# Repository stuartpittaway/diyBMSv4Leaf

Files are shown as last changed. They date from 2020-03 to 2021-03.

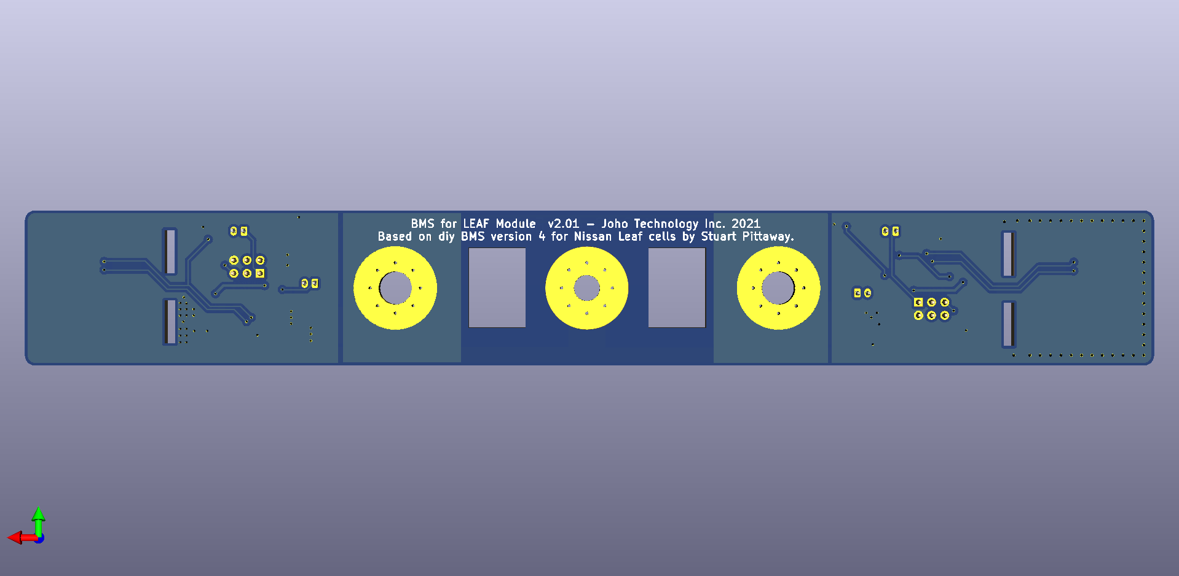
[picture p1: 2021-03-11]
Back-Design.png

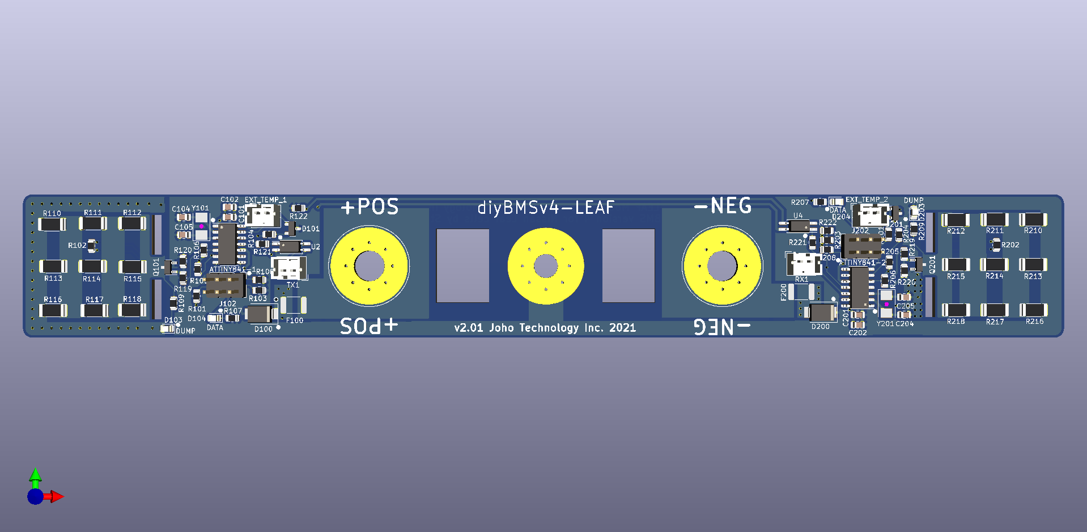
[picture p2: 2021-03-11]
Front-Design.png

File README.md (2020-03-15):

# diyBMS v4

Version 4 of the diyBMS for Nissan Leaf Cells

Do it yourself battery management system for Lithium ion battery packs/cells

This circuit revision has been made by George Boudreau - using the original v4 BMS design by Stuart Pittaway.

To contact George, please message on https://community.openenergymonitor.org/

# Videos on how to use and build

https://www.youtube.com/stuartpittaway

# CODE/SOFTWARE

Software and code for the modules and controller can now be found in a seperate repo

https://github.com/stuartpittaway/diyBMSv4Code

# WARNING

This is a DIY product/solution so don’t use this for safety critical systems or in any situation where there could be a risk to life.  

There is no warranty, it may not work as expected or at all.

The use of this project is done so entirely at your own risk.  It may involve electrical voltages which could kill - if in doubt, seek help.

The use of this project may not be compliant with local laws or regulations - if in doubt, seek help.

# License

This work is licensed under a Creative Commons Attribution-NonCommercial-ShareAlike 2.0 UK: England & Wales License.

https://creativecommons.org/licenses/by-nc-sa/2.0/uk/

You are free to:
* Share — copy and redistribute the material in any medium or format
* Adapt — remix, transform, and build upon the material
The licensor cannot revoke these freedoms as long as you follow the license terms.

Under the following terms:
* Attribution — You must give appropriate credit, provide a link to the license, and indicate if changes were made. You may do so in any reasonable manner, but not in any way that suggests the licensor endorses you or your use.
* Non-Commercial — You may not use the material for commercial purposes.
* ShareAlike — If you remix, transform, or build upon the material, you must distribute your contributions under the same license as the original.
* No additional restrictions — You may not apply legal terms or technological measures that legally restrict others from doing anything the license permits.

Notices:
You do not have to comply with the license for elements of the material in the public domain or where your use is permitted by an applicable exception or limitation.

No warranties are given. The license may not give you all of the permissions necessary for your intended use. For example, other rights such as publicity, privacy, or moral rights may limit how you use the material.

# Problem

A DIY Powerwall is the DIY construction of a pack of battery cells to create an energy store which can be used via inverters to power electrical items in the home. Generally cells are salvaged/second hand, and typically use Lithium 18650 cells.

Lithium batteries need to be kept at the same voltage level across a parallel pack. This is done by balancing each cell in the pack to raise or lower its voltage to match the others.

Existing balancing solutions are available in the market place, but at a relatively high cost compared to the cost of the battery bank, so this project is to design a low-cost, simple featured BMS/balancer.

# BMS Design

Design Goals: 
* Build upon my existing skill set and knowledge. 
* Building something that others can contribute to using regular standard libraries and off the shelf components.
* Build something that is inheriently safe
* Use platform.io to manage code and libraries
* Use Arduino based libraries and tools 
* Put everything on GITHUB
* Document it (always gets left to the end!)

# How it works

Controller provides human interface over Wifi/Web and also integrates with other systems like MQTT, emonCMS and Grafana.

Controller is esp8266-12e (NodeMCU v1) - although could be upgraded to ESP32 if really needed.

Controller should be able to take action on alerts/events to shut down inverters/chargers/fuses.

Each cell in a battery pack has a monitoring module.  This uses AVR ATTINY841 linked together by optoisolated serial ports for communication.

ATTINY841 provides:
* internal temperature monitoring
* external temperature monitoring
* Spare input/output for 3rd party use
* autonomous cell voltage balancing - it should still work even if controller is down

# How as v4 improved over v3?

* Code is better!
* Web interface no longer requires access to internet to download javascript libraries
* Controller provides outputs for integration with relay boards and switch gear
* Rules to control relay outputs
* Cell modules use ATTINY841 chip which provides more pins and lower power usage
* Removal of 3.3v regulator and ADUM chips lowers current usage significantly
* v3 module uses 10-12mA current constantly and v4 uses <1mA
* Dual temperature monitoring board + cells

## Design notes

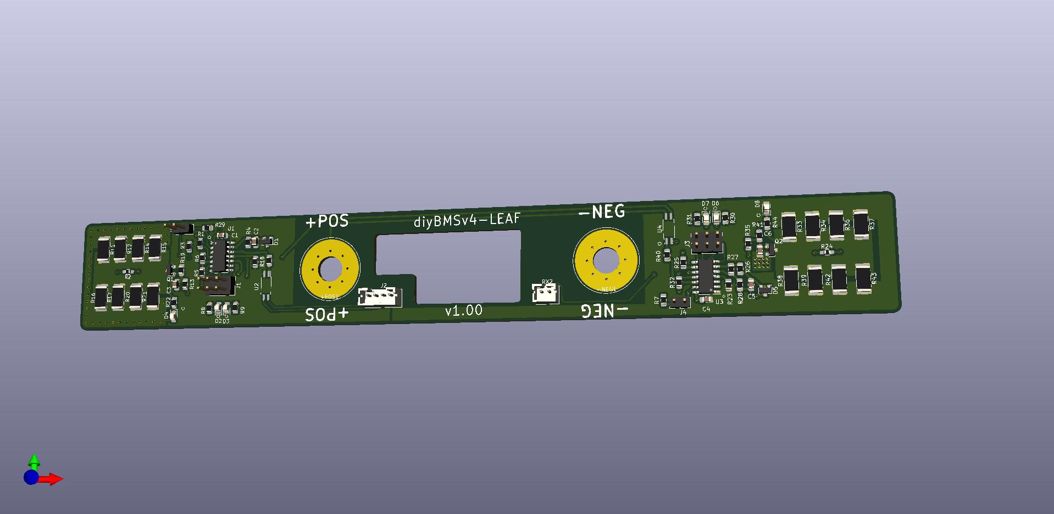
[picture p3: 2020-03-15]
diyBMS-Leaf-3D.jpg

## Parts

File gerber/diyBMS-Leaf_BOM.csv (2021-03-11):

Comment | Designator | Footprint | LCSC
ATtiny841-SSU | ATTINY841-1,ATTINY841-2 | Package_SO:SOIC-14_3.9x8.7mm_P1.27mm | C219103
100nF | C101,C201 | Capacitor_SMD:C_0805_2012Metric | C49678
1uF | C102,C202 | Capacitor_SMD:C_0805_2012Metric | C28323
22pF | C104,C105,C204,C205 | Capacitor_SMD:C_0805_2012Metric | C1804
SMBJ5.0A | D100,D200 | Diode_SMD:D_SMB | C440263
AZ432ANTR-E1 | D101,D201 | Package_TO_SOT_SMD:SOT-23 | C84139
DUMP | D103,D203 | LED_SMD:LED_0805_2012Metric | C84256
DATA | D104,D204 | LED_SMD:LED_0805_2012Metric | C84259
B2B-PH-K(LF)(SN) | EXT_TEMP_1,RX1,TX1,EXT_TEMP_2 | Connector_JST:JST_PH_B2B-PH-K_1x02_P2.00mm_Vertical | C2683610
mSMD150 | F100,F200 | Fuse:Fuse_1812_4532Metric | C70121
AVR-ISP-6 | J102,J202 | Connector_PinHeader_2.54mm:PinHeader_2x03_P2.54mm_Vertical | C65114
SM2320NSAC-TRG | Q101,Q201 | Package_TO_SOT_SMD:SOT-23 | C368560
10K | R101,R103,R108,R120,R201,R203,R208,R220 | Resistor_SMD:R_0805_2012Metric | C17414
CMFB103F3950FANT | R102,R202 | Resistor_SMD:R_0805_2012Metric | C51597
1K | R104,R204 | Resistor_SMD:R_0805_2012Metric | C17513
6.8K | R105,R205 | Resistor_SMD:R_0805_2012Metric | C17772
2.7K | R106,R206 | Resistor_SMD:R_0805_2012Metric | C17530
2K2 | R107,R109,R207,R209 | Resistor_SMD:R_0805_2012Metric | C17520
3.3OHM 3/4W | R110,R111,R112,R113,R114,R115,R116,R117,R118,R210,R211,R212,R213,R214,R215,R216,R217,R218 | Resistor_SMD:R_2010_5025Metric | C270971
510R | R119,R219 | Resistor_SMD:R_0805_2012Metric | C17734
220 | R121,R221 | Resistor_SMD:R_0805_2012Metric | 0805W8F2200T5E
4K7 | R122,R222 | Resistor_SMD:R_0805_2012Metric | C441984
EL3H7(B)(TA)-G | U2,U4 | Package_SO:SOP-4_4.4x2.6mm_P1.27mm | C32565
8MHZ Ceramic Resonator | Y101,Y201 | Crystal:Crystal_SMD_5032-2Pin_5.0x3.2mm | C115962

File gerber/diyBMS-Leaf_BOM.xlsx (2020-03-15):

COMMENT | Designator | Footprint | LSCS Part #
ATTing841-SSU | U1, U3 |  | C219103
100nF | C4,C1 | 0805 | C49678
2.2uF | C2, C5 | 0805 | C49217
10uF | C6,C3 | 0805 | C15850
AZ432ANTR-E1 | D5,D1 | SOT-23 | C84139
Green | D6,D2 | 0805 | C2297
Blue | D7,D3 | 0805 | C2293
RED | D8,D4 | 0805 | C84256
AO3400A | Q2,Q1 | SOT-23 | C20917
4.7K ohm | R10,R32 | 0805 | C17673
33 ohm | R21,R20,R17,R16,R15,R14,R12,R11,R42,R39,R38,R37,R36,R34,R33,R43 | 2512 | C53728
10K | R23,R1 | 0805 | C17414
NCP18WB473J03RB | R24,R2 | 0603 | C86142
1K ohm | R26,R4 | 0805 | C17513
68K | R27,R5 | 0805 | C17801
27K | R28,R6 | 0805 | C17593
47K ohm | R29,R41,R25,R19,R3,R7 | 0805 | C17713
510 ohm | R40,R18,R35,R13 | 0805 | C17734
2.2K | R44,R31,R30,R22,R9,R8 | 0805 | C17520
EL3H7(B)(TA)-G | U4,U2 | SOP-4_4.4x2.6mm_P1.27mm | C32565
B2B-PH-K-S (LF)(SN) | RX |  | C131337
B4B-PH-K(LF)(SN | J2 |  | C265289

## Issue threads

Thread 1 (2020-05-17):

Gerber&BOM update

baranchuk, 2020-05-17:
Need to correct gerber&BOM files to use with jlcpcb. Change thermistor to 0402 and AZ432ANTR-E1 to analog

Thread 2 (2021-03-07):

A updated version (still alpha) is being made by Allan Lind. How to intergrade/link the information?

robouden, 2021-03-07:
https://github.com/allanlind/diyBMSv4Leaf/releases/tag/v2.00-alpha

allanlind, 2021-03-07:
Hi Stuart, I am new to Github, and I hope my revised Leaf version of BMS can be useful. Let me know if you would like me to change anything.
Regards,
Allan

kchiem, 2021-03-09:
I got this error on JLCPCB:

"Failed processing the CPL file."

allanlind, 2021-03-09:
Stuart,
I used your version 4.40 that you release less than 2 weeks ago. It has the same identical parts. I increased the spacing and put copper under the resistors where possible and some slits to try to decouple the heat from the other parts of the board. Take a look at the PNG files to see the layout.
Allan

stuartpittaway, 2021-03-09:
Two weeks is a long time in diyBMS :-)

The original resistors were not high wattage, so were swapped out with 9 3/4W resistors.

Heres the latest picture of the 4.40 boards
https://github.com/stuartpittaway/diyBMSv4/blob/master/ModuleV440/ModuleV440.png

Additionally, JLCPCB didn't have stock of the original resistors!

allanlind, 2021-03-11:
Stuart, I updated the resistors. Please feel free to look at my updated version here:
https://github.com/allanlind/diyBMSv4Leaf/tree/diyBMSv4Leaf-ver2

allanlind, 2021-04-04:
Stuart, I got the new Leaf module boards back and will test them as the rest of the parts arrive. In the meantime I have a question for you regarding integration of diyBMS with Inverters. I have a Trinabess Power Box which has RS485 and I am wondering if it might be possible to get the diyBMS to work with it. Perhaps I can sniff the RS485 packets and figure out how to do things like set the charging current. Have you included any code in the controller for this by any chance?
Allan

stuartpittaway, 2021-04-05:
Hi Allan, Apart from testing that the RS485 works, I've not added in any additional code to talk to external devices (yet).  That is the plan though.

First item will be the new current shunt I've built (Modbus over RS485).

stuartpittaway, 2021-06-07:
@allanlind how is the updated LEAF board design?  A number of people have been asking about it.

allanlind, 2021-06-07:
Hi Stuart,
I have a bunch finished but have not been able to test as yet.
The holdup is with the Banggood displays.
Three units finally arrived but were banged up good!
Now they are saying they are out of stick again.
So I will have to accept a refund and look elsewhere.
Additionally I am still trying to source a suitable Leaf battery pack.
I should have something working soon.
I suspect the design is good though.

Allan Lind
Keitai (JPN): 080-5008-8699
Mobile (NZ): +64-22-100-8909
Sent from iPhone

On 8/06/2021, at 3:06 AM, Stuart Pittaway ***@***.***> wrote:

@allanlind<https://github.com/allanlind> how is the updated LEAF board design? A number of people have been asking about it.

—
You are receiving this because you were mentioned.
Reply to this email directly, view it on GitHub<https://github.com/stuartpittaway/diyBMSv4Leaf/issues/2#issuecomment-856015403>, or unsubscribe<https://github.com/notifications/unsubscribe-auth/ABNZKP676IKVMPXXMNB3EDLTRTN5VANCNFSM4YXLFYZA>.

allanlind, 2021-11-13:
The attachments won’t go through.

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

stuartpittaway, 2021-11-13:
Hi, the CANBUS doesn't really have a debug mode, but can be switched on by enabling the victron integration.

At the moment it is sending data out in victron BMS format.

allanlind, 2021-11-13:
How can I can send you photos?

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

stuartpittaway, 2021-11-13:
You can attach photos to GitHub issues

allanlind, 2021-11-13:
thanks,
I created a new issue for the CANBUS connection please take a look

allanlind, 2021-11-13:
New 7 in 1 Leaf module.

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

N1c084, 2022-03-07:
hi allanlind
Nice , did you post the files somewhere (gerber, schematic bom pcl....) ?
thanks

allanlind, 2022-03-15:
N1c084, I have uploaded 3.02 ver BOM, POS and GERBER files for this huge 7 module board. You have everything you need to get these manufactured at JLPCB. I had 20 boards made already. There was a small mistake which required drilling out a via on each board which I fixed in this 3.02 version. The only problem is going to be getting all the components. You may have to substitute for slightly different spec passives. Now the ATMEL CPUs are a real problem as JLCPCB never have them in stock. I had to manually solder 280 CPUs with an improvised cut down stencil and a rework station. It took a few days of work to do that, and not something to look forward to. You may have to look at getting board assembly done somewhere other than JLPCB.
As for the Schematic I will try to add the PDF file, but I first need to figure out why it's not displaying correctly.

N1c084, 2022-03-20:
Thanks you. i will look later. Do ou mount the PCB directly on terminals of cells or to you first mount the connexion bar witch can support more current flow?
Regards

allanlind, 2022-03-21:
The design includes high current path so no need to use bus bars. The board goes directly onto the modules.
I’ll double check the pos file for correct rotation.

N1c084, 2022-03-21:
Ok , please, how much current can pass trough the PCB?
I try to load pos file on Jl pcb and all 3 pin mosfet and regulator are
@180degree on final check screen.thanks

Le lun. 21 mars 2022 à 01:20, GammaKiwi ***@***.***> a écrit :

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

allanlind, 2022-03-21:
OK I’ll update the pos file tomorrow. The pcb tracks are likely good for 40A. I have 8 of these boards in parallel and have run 180A total without overheating which works out to 22A per board. But if you want to run very high current you can always put the original Leaf bus bars on as well.

allanlind, 2022-03-21:
I double checked the pos file and it is actually correct. Here is the response from JLCPCB:

"having trouble with pos file. In kicad all components are oriented correctly in 3D view
but when I check your layout preview the transistors and voltage references are rotated 180 deg"

Wick 09:50
Actually, sometimes not all files can be detected/recognized correctly by our system ,so you can ignore it and proceed.
Our engineer will check your file and if any issues, they will get you informed. Our engineer will correct it and you could check the DFM they make later.

N1c084, 2022-03-21:
ok thanks this is a JLPCB bug
You have 8 board in //, how do you drive the coupling of string (contactor for each string)  and security (open only the fail string and never closed a string with too diffèrent voltage /SOC from other)?
one controler board per  string?

N1c084, 2022-03-21:
and do you know if this board design is compatible with gen 4?
 i neeed to look if space between terminals are the same before put an order

allanlind, 2022-03-21:
Not sure what you mean by Gen 4. My design is for 24kwh Gen 1 or Gen 2 modules only. You cannot use 30 and 40kWh modules as these are different and the positive and negative terminals are arranged differently.
I have used 8 Chint 2 pole DZ158-125 MCBs to isolate each bank. These MCB are rated for 415VAC or 110VDC per pole and can break up to 125A DC.

allanlind, 2022-03-21:
Detail showing how the modules are wired to the MCBs.
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

This photo shows the bas bars where all 8 banks come together. You can also see a 160A per pole Circuit Breaker which allows me to isolate the two 5kW Victron inverters which are in parallel.
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
Breaking capacity on this circuit breaker is 40,000A.

N1c084, 2022-03-21:
thanks , nice.
But if a cell fail by going undervoltage or become hot, you can not isolate this string automatically , it can be better to add such security feature by driving a relay on each string?

allanlind, 2022-03-22:
Not sure how one would do that.

N1c084, 2022-03-22:
> Not sure how one would do that.

@stuartpittaway , any idea to drive one relay per string with voltage control between string before closed and also ability to isolate 1 faulty string and stay other alive?  Thanks

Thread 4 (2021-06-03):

CPL File missing

dakoal, 2021-06-03:
There is no "JLC" named BOM and CPL FIle here.
For the "normal" modules there are extra JLCPCB BOM and CPL files.

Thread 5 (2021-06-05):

kicad.pcb file can't be opened.

dakoal, 2021-06-05:
Can't open the file diyBMS-Leaf.kicad_pcb.
It says I need to install newer KiCad Version, but already have the newest.

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

stuartpittaway, 2021-06-07:
I think the last submitted update must have used the experimental version of KICAD 6, hence the issue with opening the board.

I don't maintain this version of the design, so would need somebody to help revive this version of the boards.

allanlind, 2021-11-13:
Oh sorry, just saw this now. Yes you need to download the Daily Build version of Kicad and you can then open the files.

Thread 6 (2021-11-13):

Trinabess Power Box Experiment

allanlind, 2021-11-13:
Experiment to connect Trinabess Power Box to DIYBMS Controller with CANBUS.
I got the CANBUS pinout from the US2000 battery as the Trinabess Inverter connects to it using the supplied cable. See pinout in attached image.

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

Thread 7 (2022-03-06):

Center tap as part of the PCB seems bad?

gesso15, 2022-03-06:
The initial design of the leaf board had the center tap on a wire that plugged in, this way you could attach the center tap before you attached the outer taps. This prevented you from accidentally sending 2s worth of voltage into the second monitor if the outer taps touched before the center tap.

I don't really understand how to do that with the current design that has the center tap as part of the PCB, without flexing the PCB.

Am I missing something?

N1c084, 2022-03-07:
originaly you connect the 2 outer first and after the center?
it is like a switch, in this design , noway to shutdown bms but no functionnal pb

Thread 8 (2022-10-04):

Leaf install photo

Deftaudio, 2022-10-04:
Hi,
I have 19 Leaf modules loaded in Vectrix VX1 EV scooter. Would love to use your adoption of DIYbms there.
Would you please share any photo of the finished/installed module. Just want to understand how it sits on buss bars and mounting.
Thank you!

stuartpittaway, 2022-10-05:
Hi, I didn't actually build/design the leaf modules they were done by the community over at the OpenEnergyMonitor forum.

You are best to ask over there for help.

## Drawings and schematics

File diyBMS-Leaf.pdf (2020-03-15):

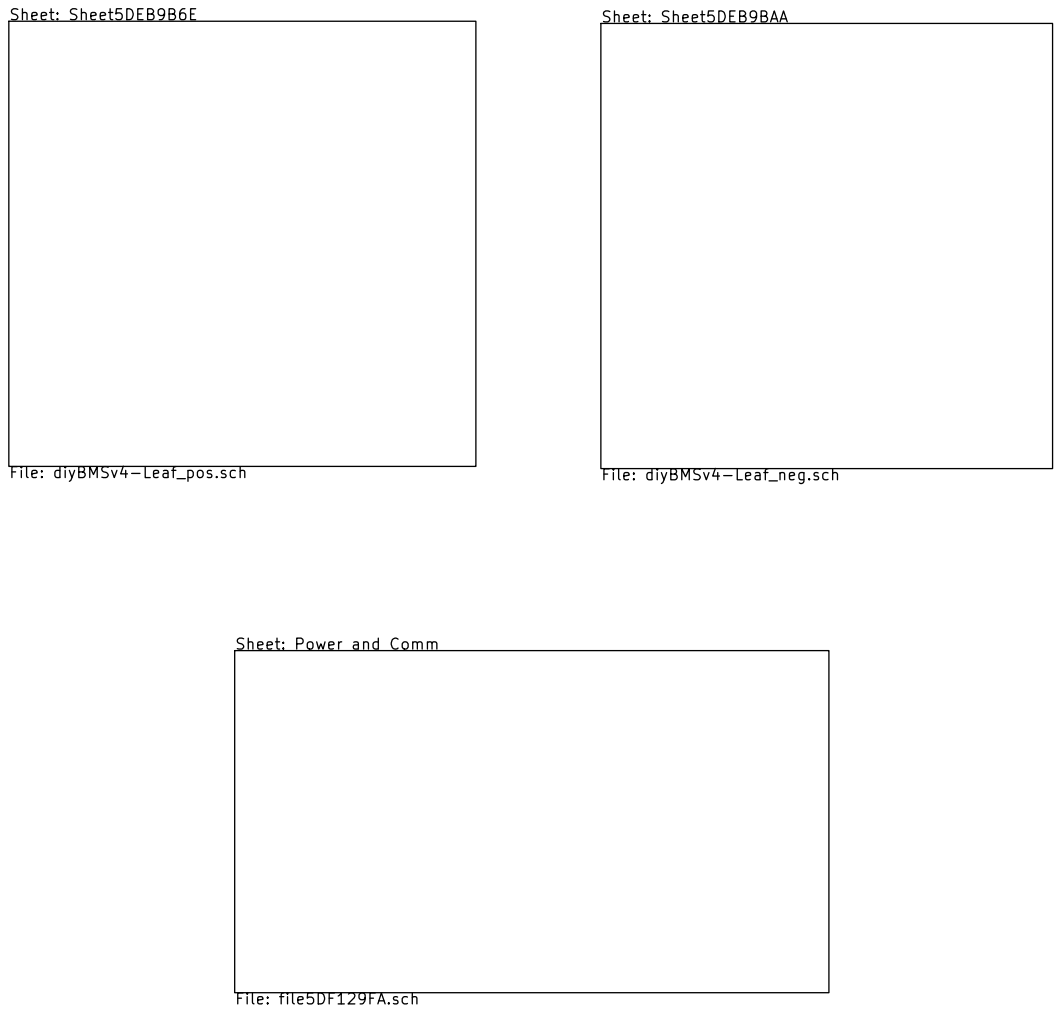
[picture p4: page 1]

File: diyBMSv4-Leaf_neg.sch Sheet: Power and Comm

Id: 1/4 Title: diyBMS-LEAF

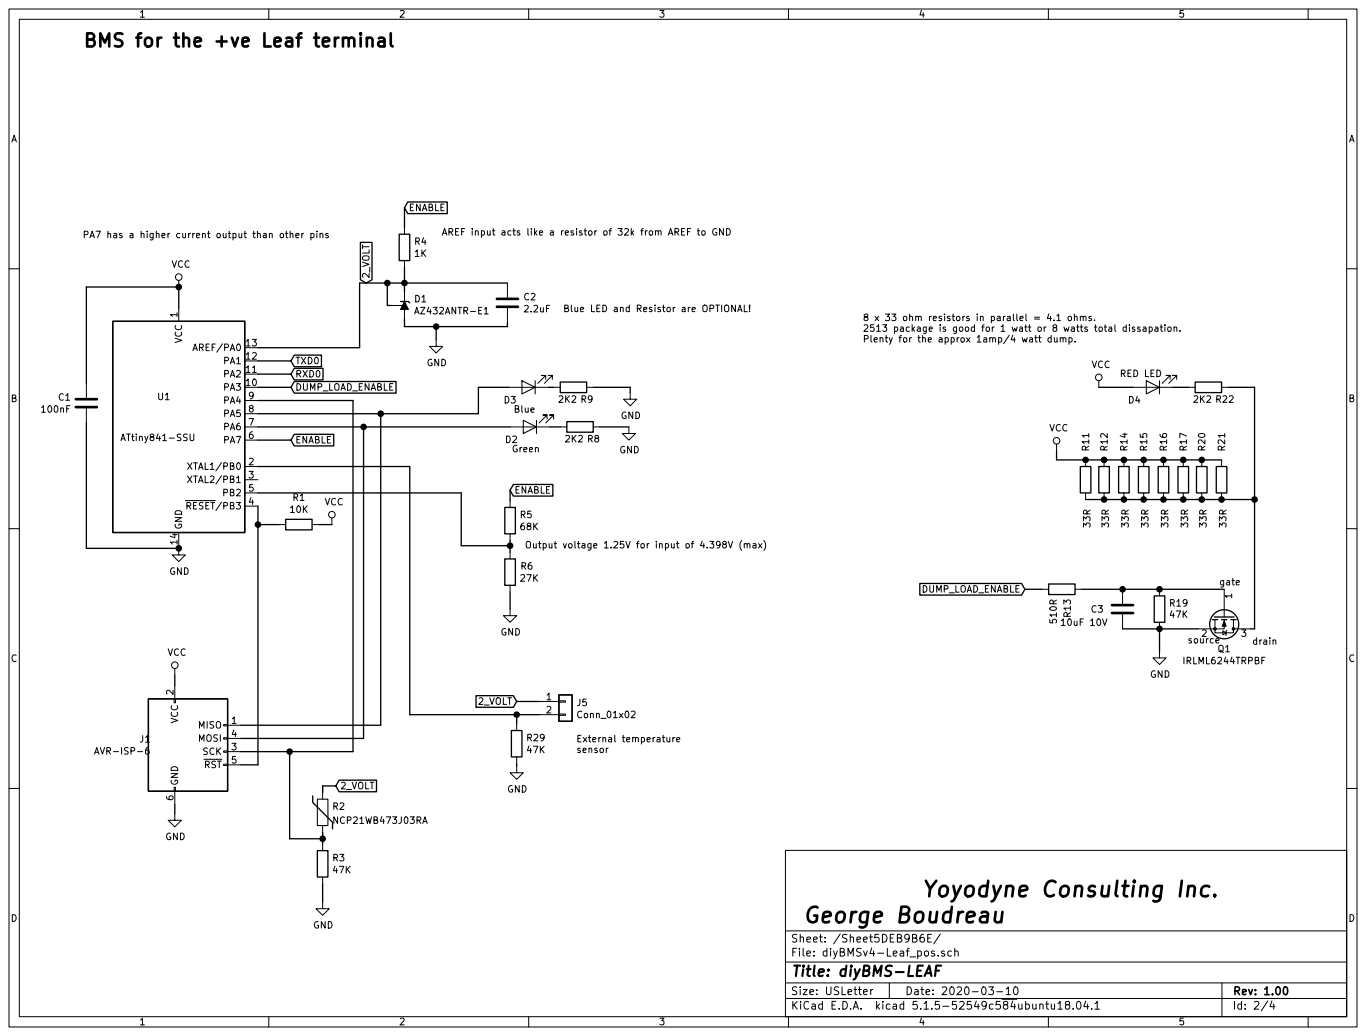
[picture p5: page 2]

BMS for the +ve Leaf terminal
2_VOLT ENABLE 2_VOLT

AREF input acts like a resistor of 32k from AREF to GND

gate PA7 has a higher current output than other pins

1 PA3 10 PA2 11 PA1 12 AREF/PA0 13 GND 14 XTAL1/PB0 2 XTAL2/PB1 3 RESET/PB3 4 PB2 5 PA7 6 PA6 7 PA5 8 PA4 U1 9 ATtiny841-SSU R21 33R R20 33R

8 x 33 ohm resistors in parallel = 4.1 ohms.
2513 package is good for 1 watt or 8 watts total dissapation.
Plenty for the approx 1amp/4 watt dump.

2 SCK 3 MOSI 4 RST 5 GND

File: diyBMSv4-Leaf_pos.sch Sheet: /Sheet5DEB9B6E/ Yoyodyne Consulting Inc.

Id: 2/4 Title: diyBMS-LEAF

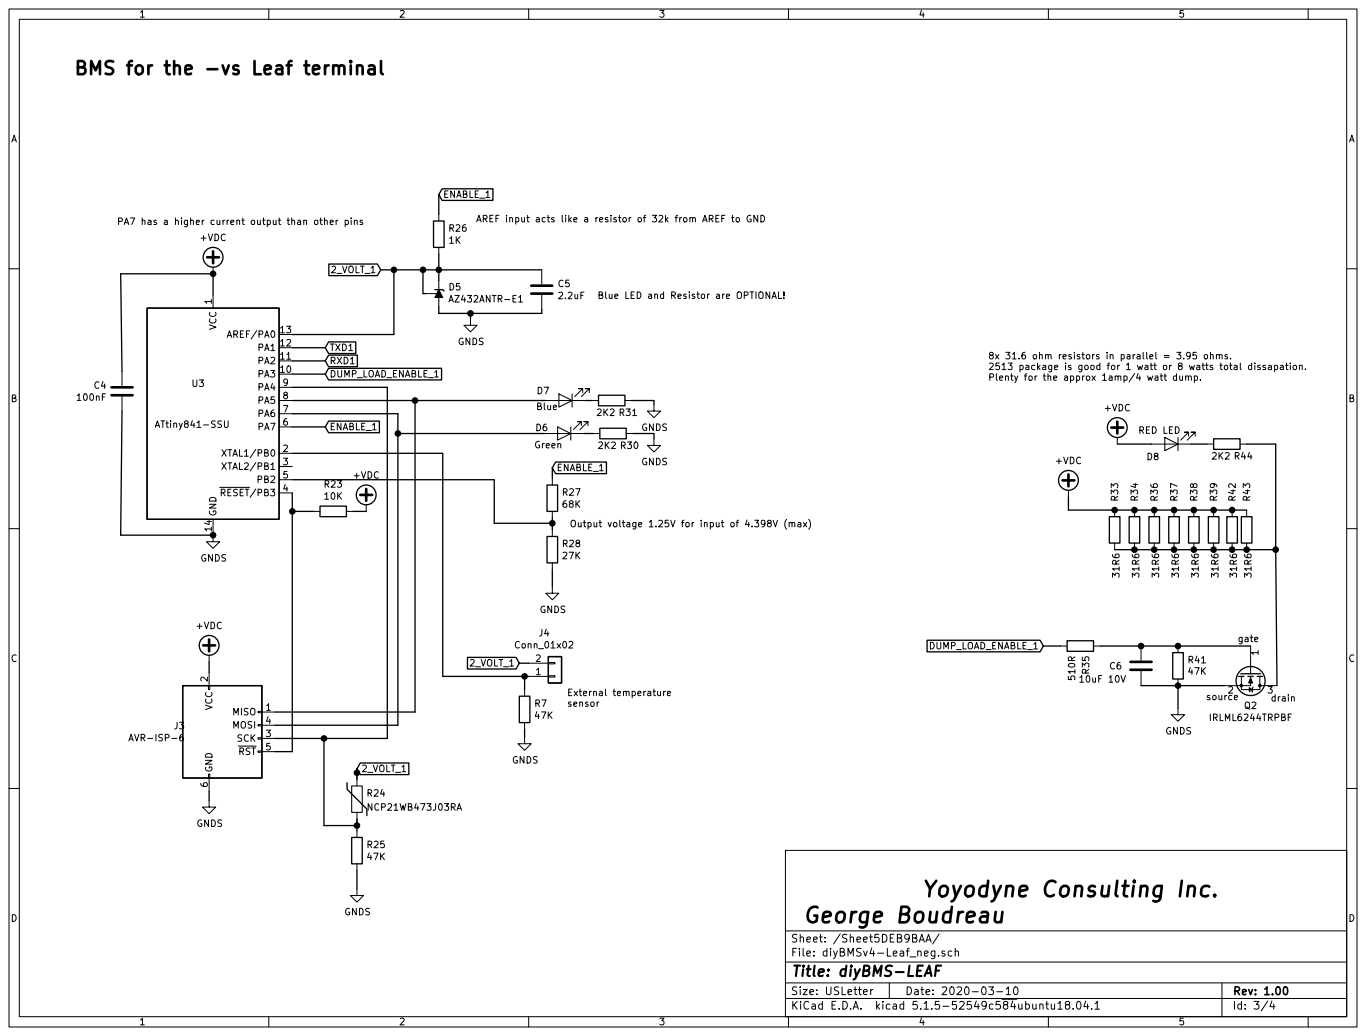
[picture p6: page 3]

BMS for the -vs Leaf terminal

AREF input acts like a resistor of 32k from AREF to GND

2_VOLT_1 TXD1 RXD1 PA7 has a higher current output than other pins

1 PA3 10 PA2 11 PA1 12 AREF/PA0 13 GND 14 XTAL1/PB0 2 XTAL2/PB1 3 RESET/PB3 4 PB2 5 PA7 6 PA6 7 PA5 8 PA4 U3 9 ATtiny841-SSU R43 31R6 C6

gate Blue LED and Resistor are OPTIONAL!

2513 package is good for 1 watt or 8 watts total dissapation.

+VDC
R23

Output voltage 1.25V for input of 4.398V (max)

2 SCK 3 MOSI 4 RST 5 GND

File: diyBMSv4-Leaf_neg.sch Sheet: /Sheet5DEB9BAA/ Yoyodyne Consulting Inc.

Id: 3/4 Title: diyBMS-LEAF

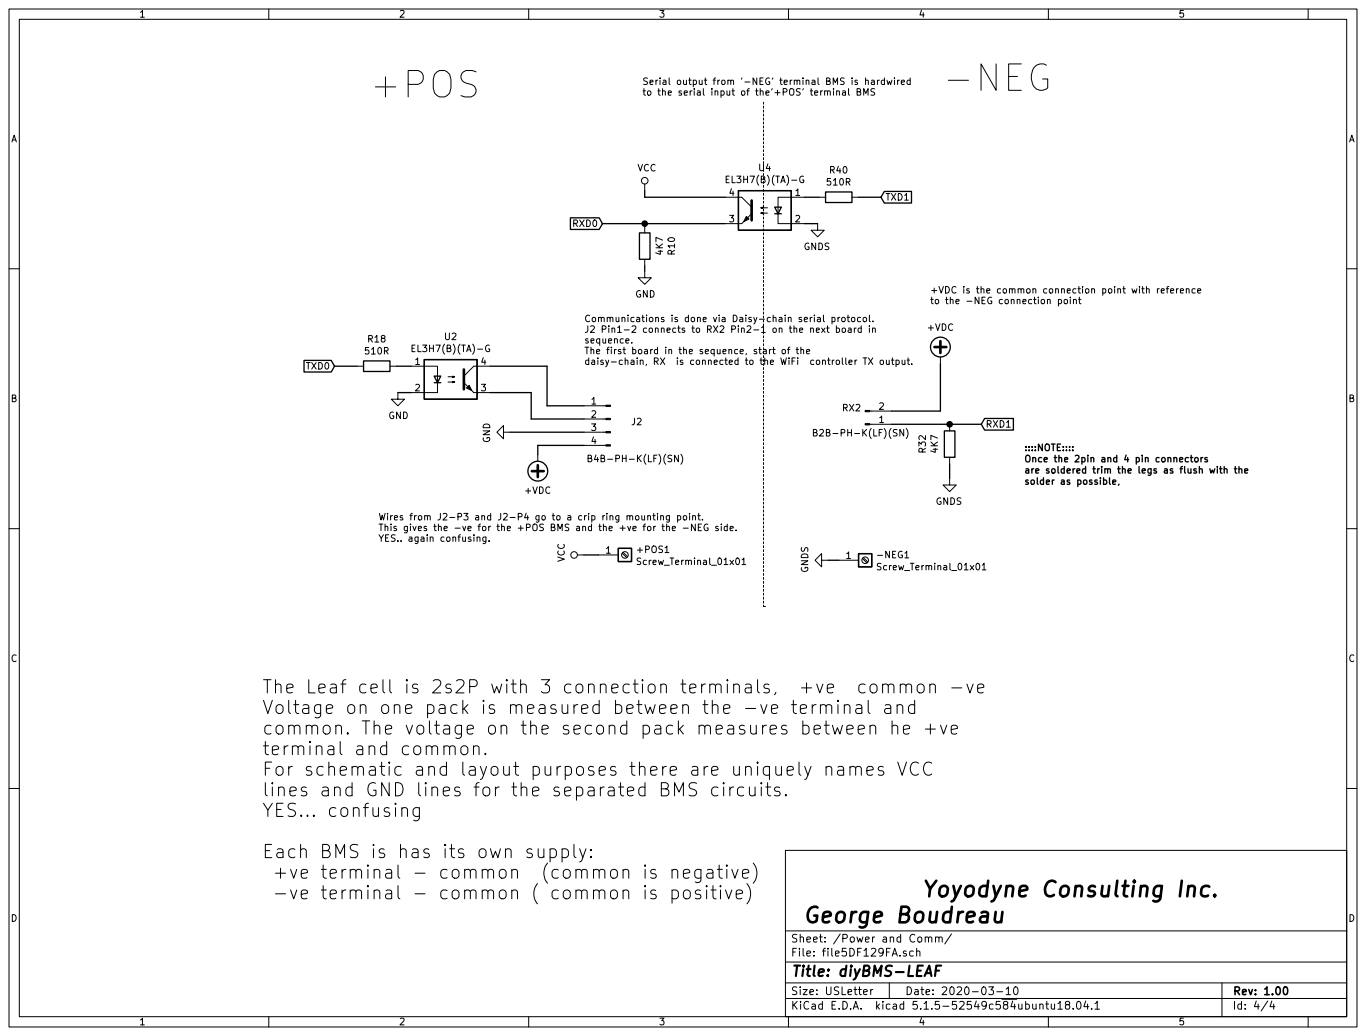
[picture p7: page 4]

+VDC is the common connection point with reference
to the -NEG connection point

Communications is done via Daisy-chain serial protocol. J2 Pin1-2 connects to RX2 Pin2-1 on the next board in

sequence. The first board in the sequence, start of the

daisy-chain, RX is connected to the WiFi controller TX output.

J2 B4B-PH-K(LF)(SN) GND

::::NOTE:::: Once the 2pin and 4 pin connectors

are soldered trim the legs as flush with the
solder as possible,

Wires from J2-P3 and J2-P4 go to a crip ring mounting point.
This gives the -ve for the +POS BMS and the +ve for the -NEG side.
YES.. again confusing.

Voltage on one pack is measured between the -ve terminal and
common. The voltage on the second pack measures between he +ve
terminal and common.
For schematic and layout purposes there are uniquely names VCC
lines and GND lines for the separated BMS circuits.
YES... confusing

Each BMS is has its own supply:
-ve terminal - common ( common is positive)

File: file5DF129FA.sch Sheet: /Power and Comm/ Yoyodyne Consulting Inc.

Id: 4/4 Title: diyBMS-LEAF

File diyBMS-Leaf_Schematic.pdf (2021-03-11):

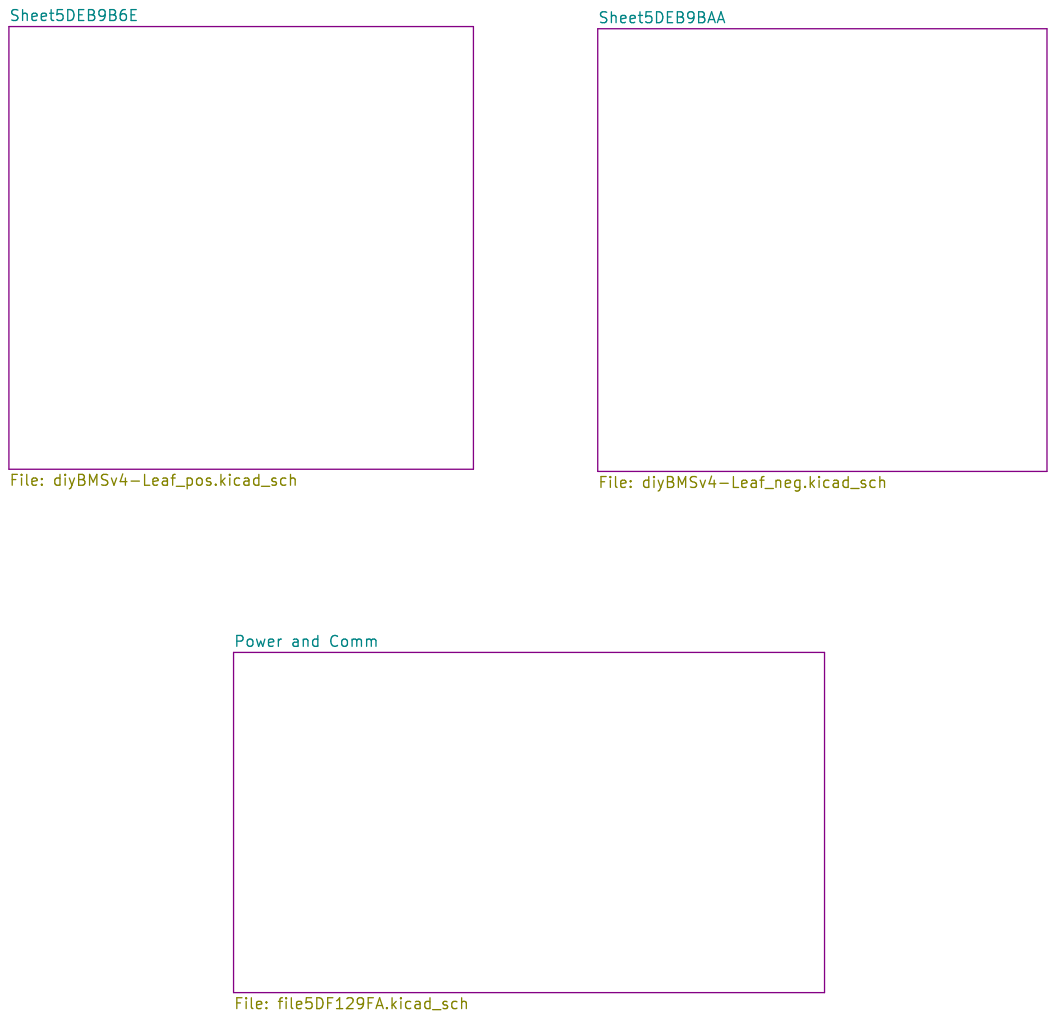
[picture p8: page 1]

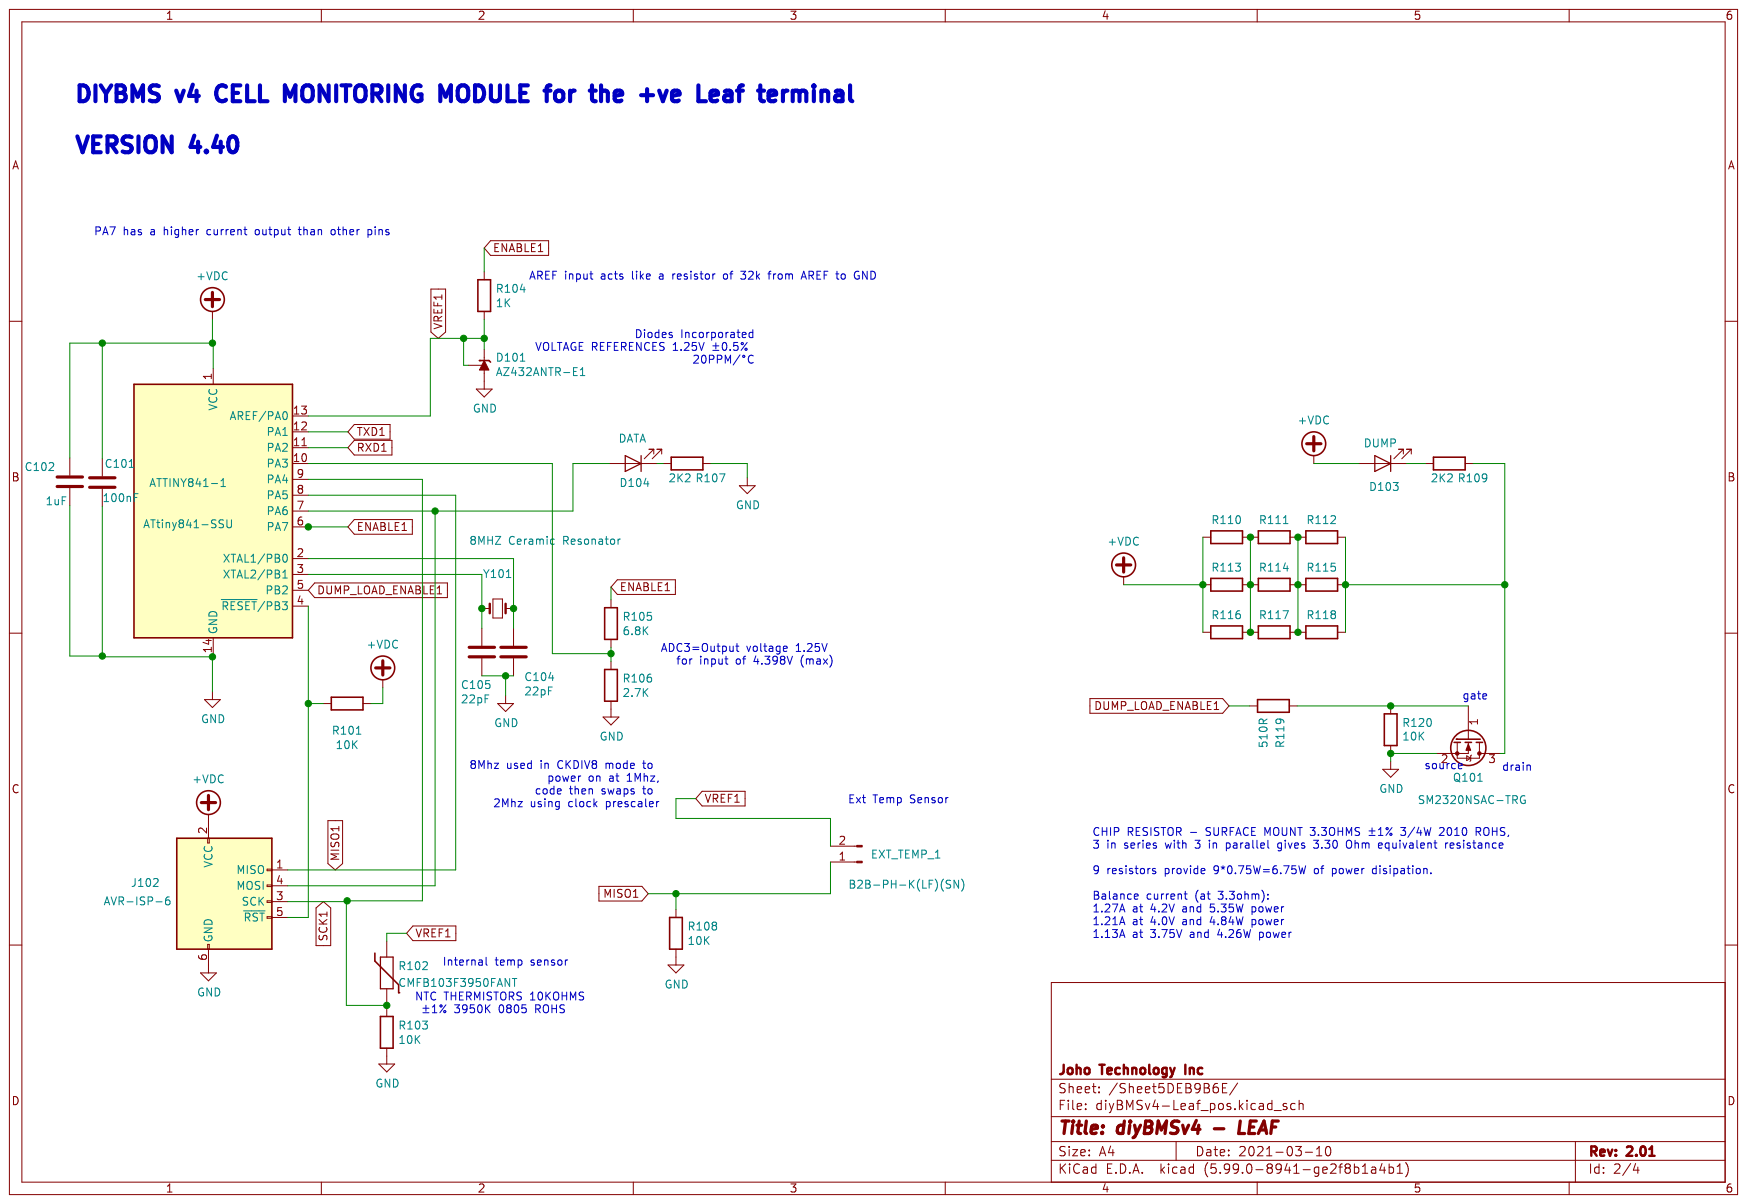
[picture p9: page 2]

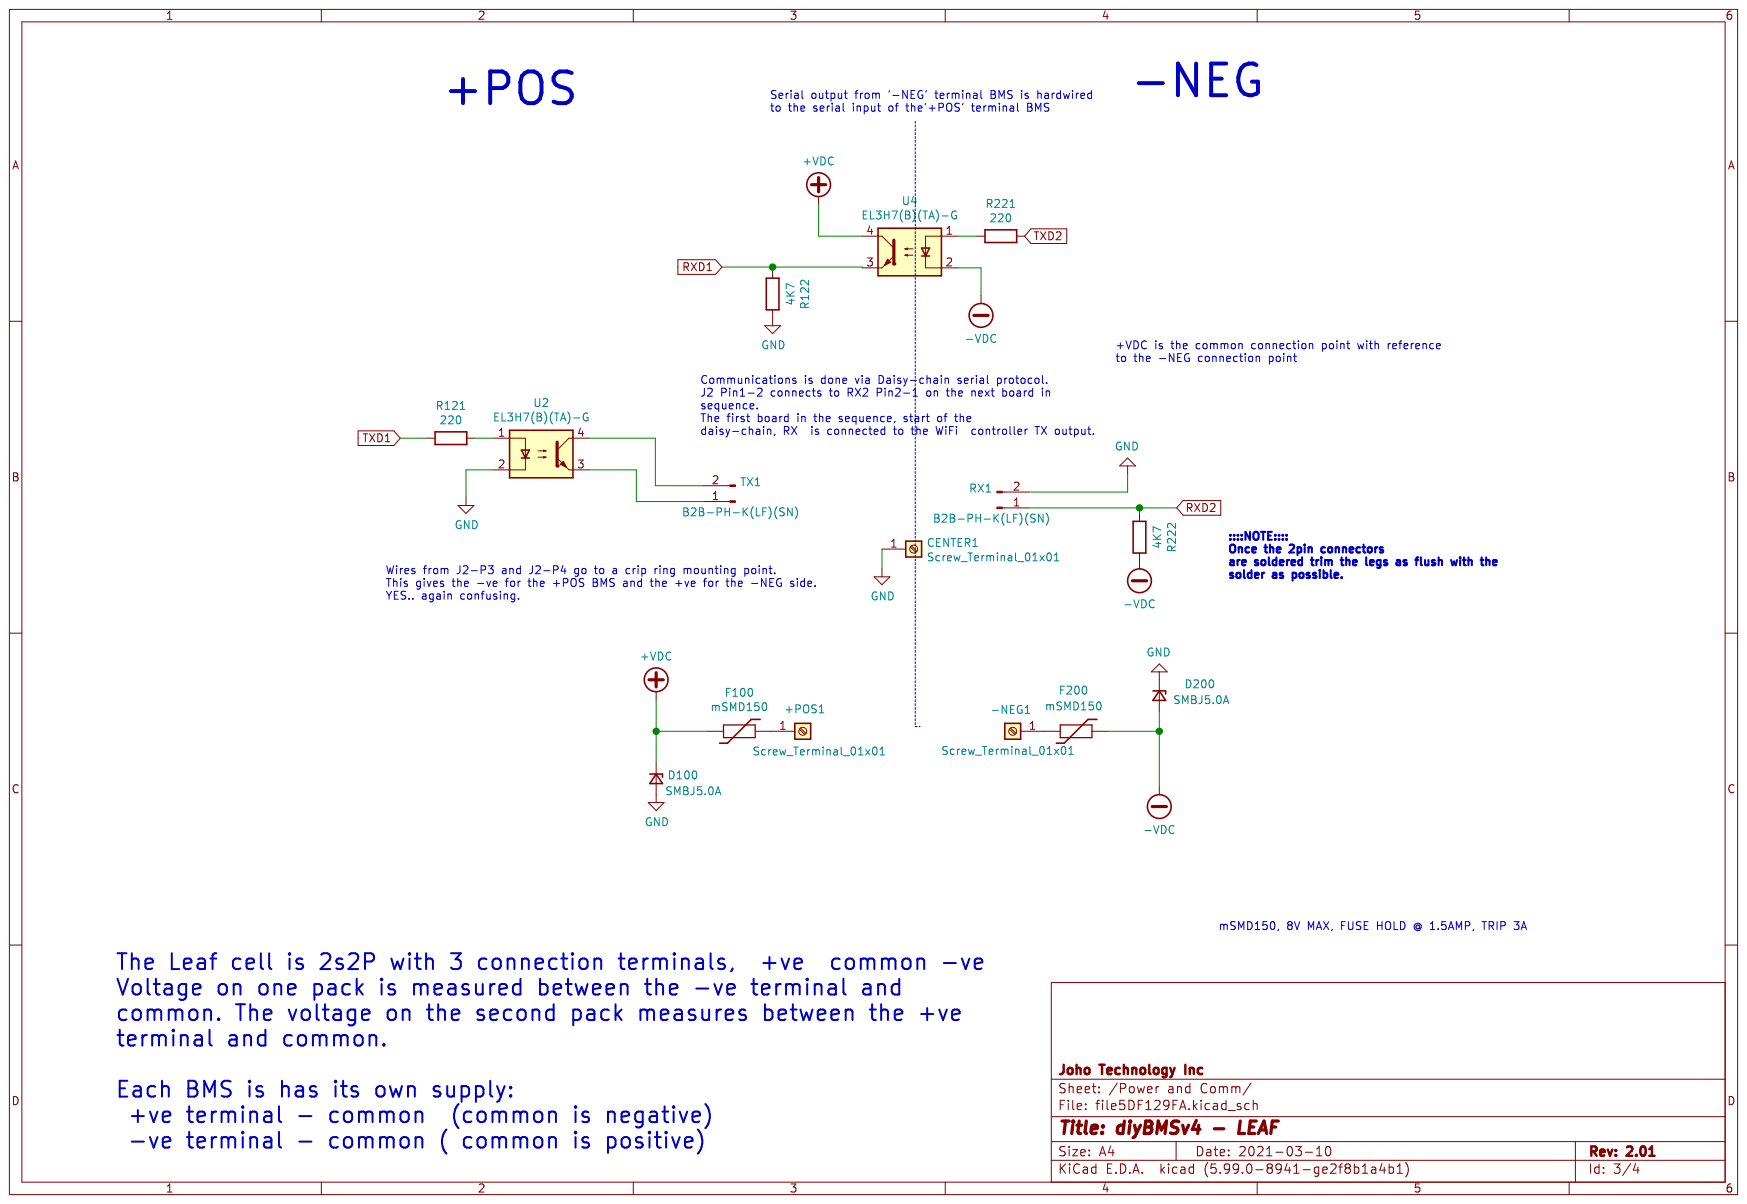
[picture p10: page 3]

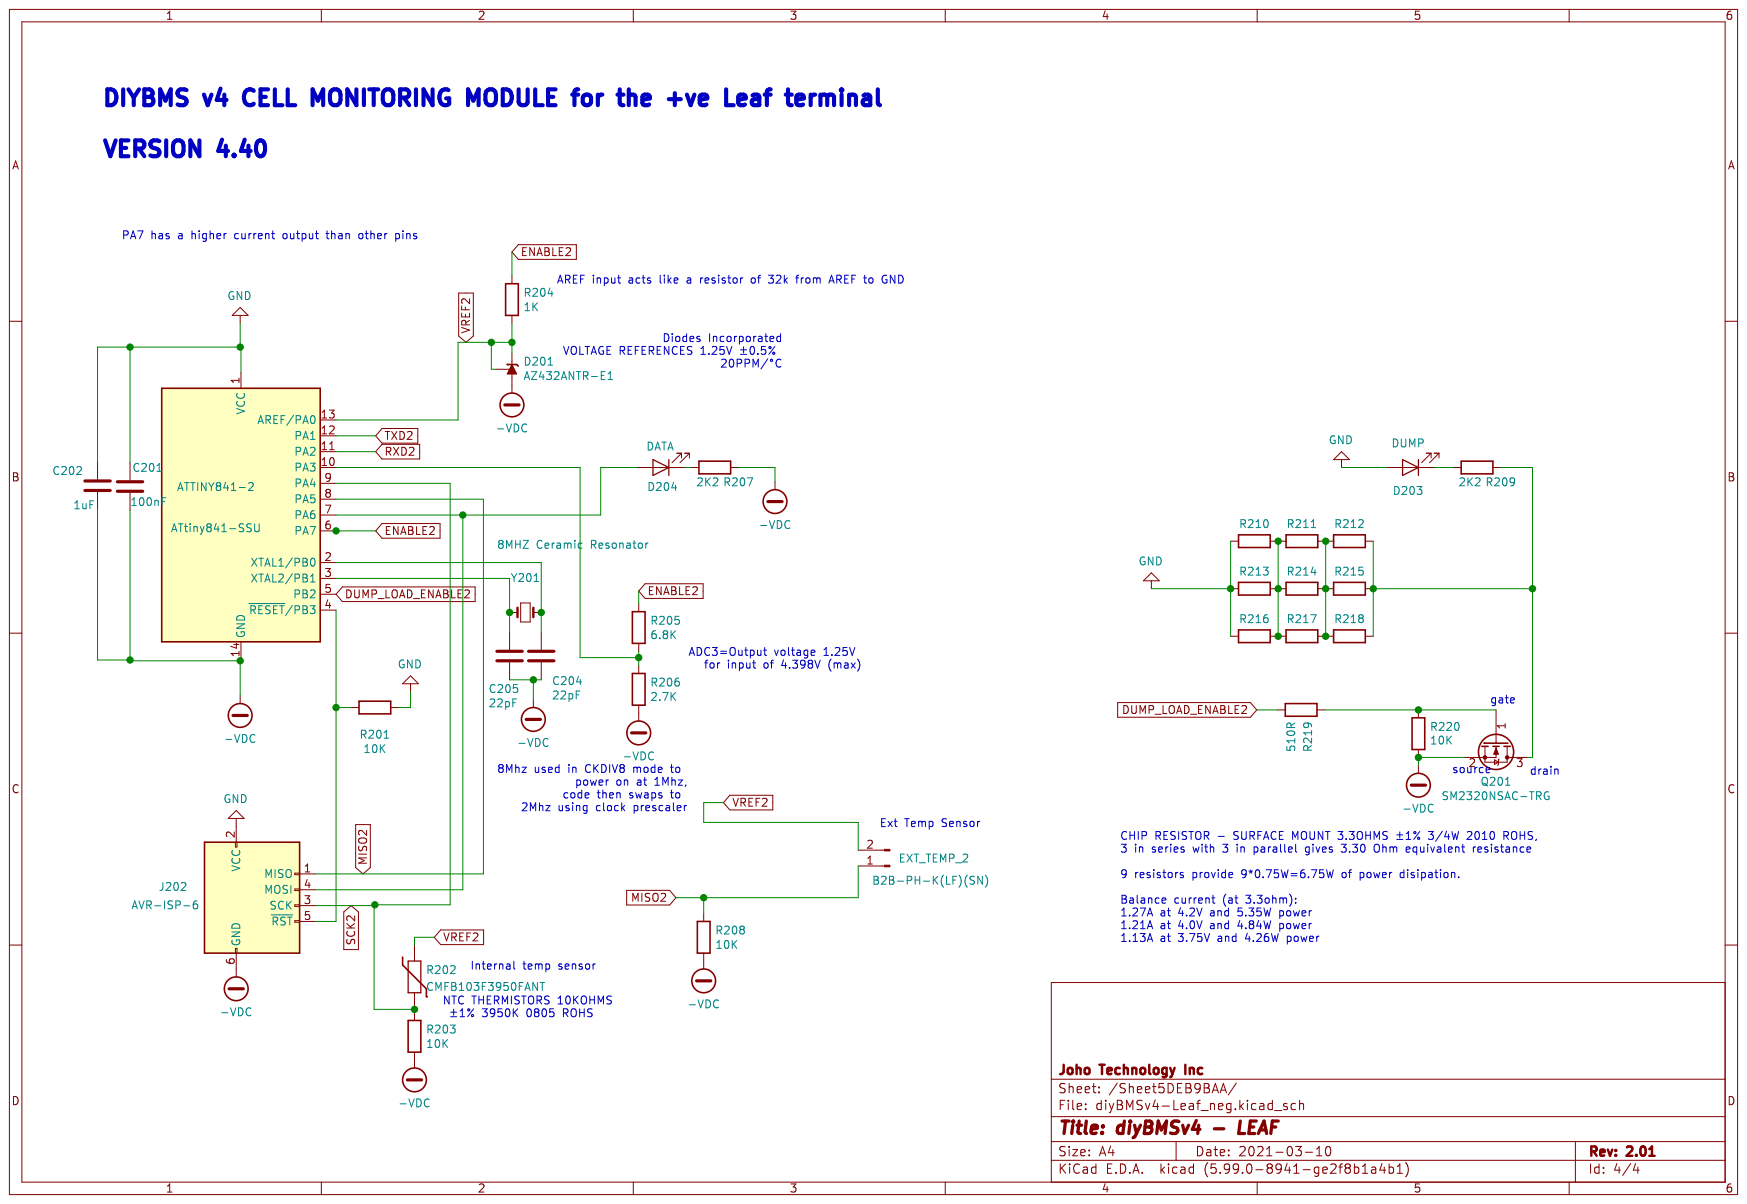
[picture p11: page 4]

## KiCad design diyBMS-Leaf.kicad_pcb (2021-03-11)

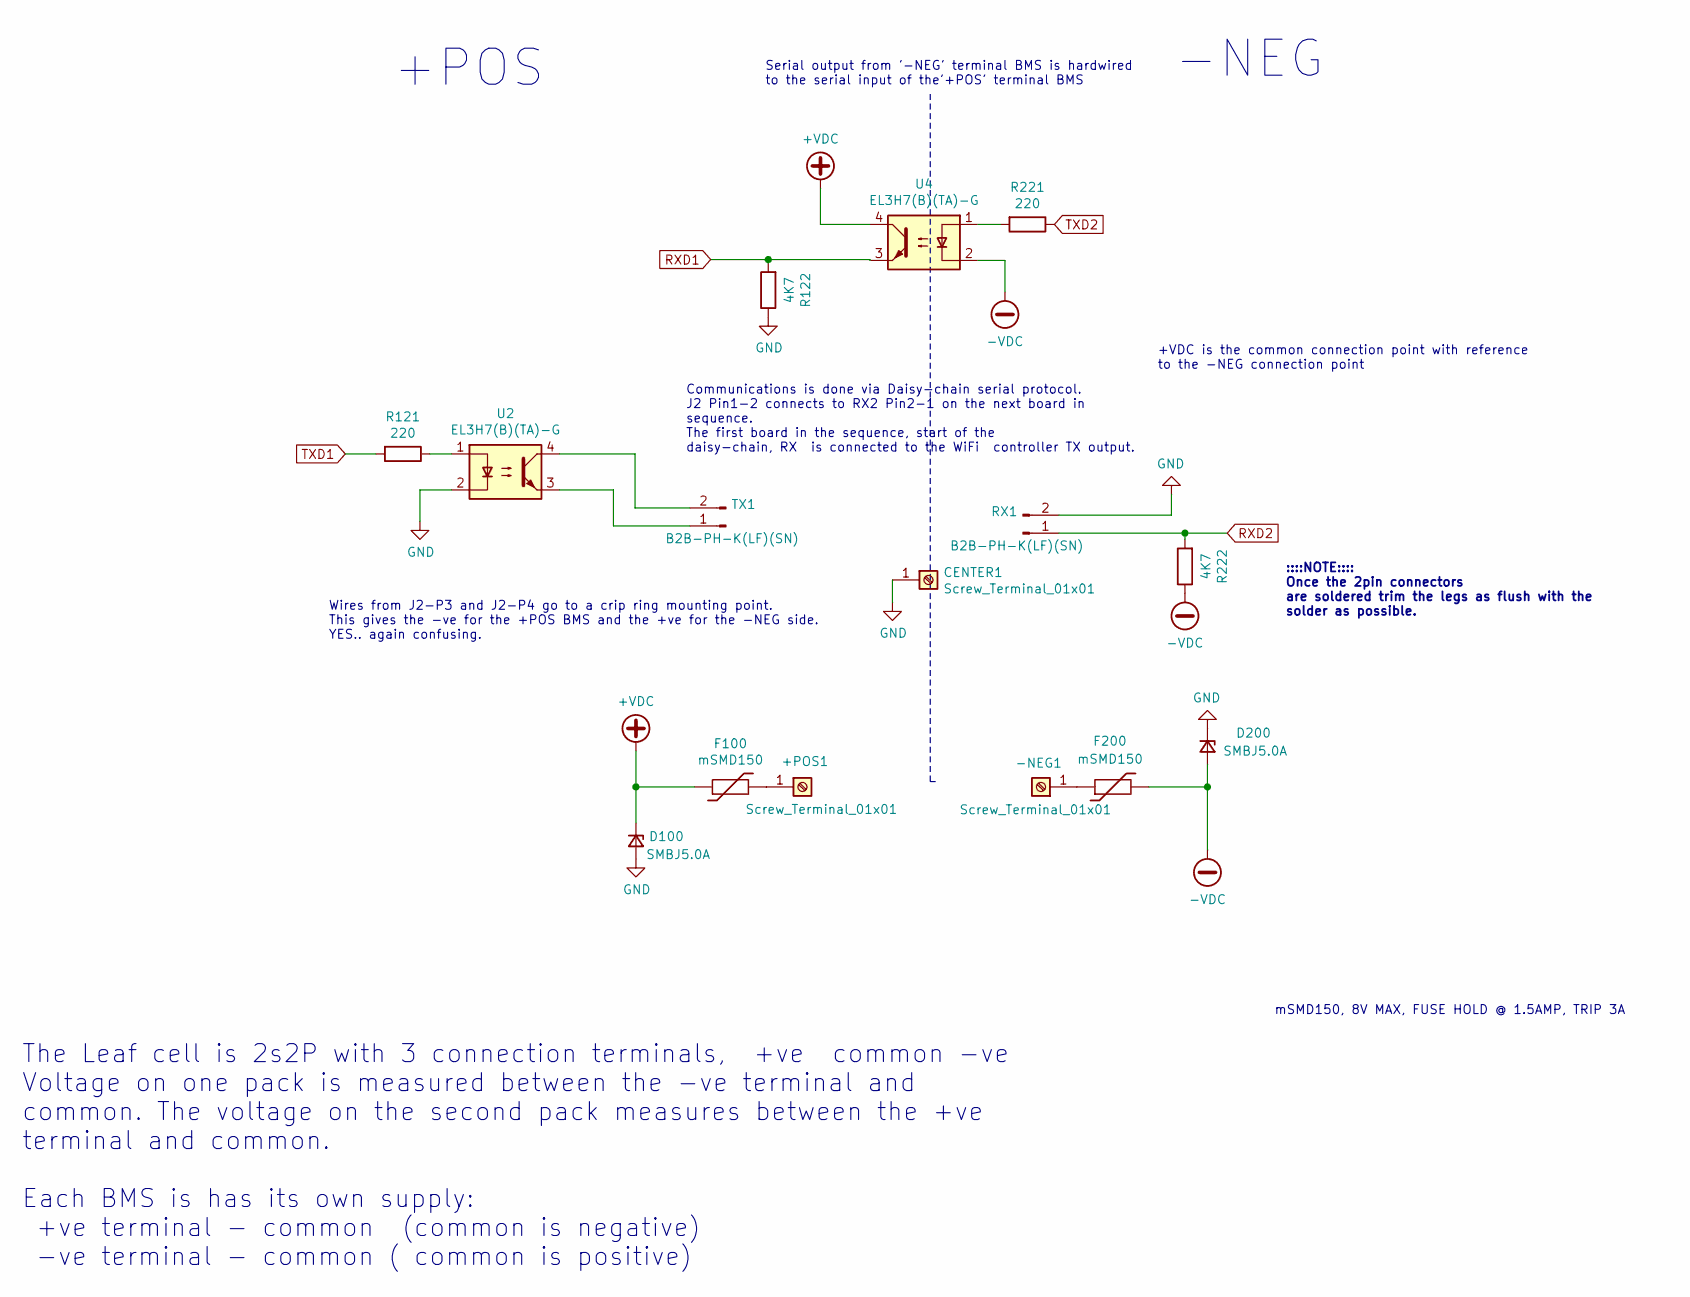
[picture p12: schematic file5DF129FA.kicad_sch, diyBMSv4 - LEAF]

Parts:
+POS1: Screw_Terminal_01x01; MountingHole_6.5mm_Pad_Via
-NEG1: Screw_Terminal_01x01; MountingHole_6.5mm_Pad_Via
CENTER1: Screw_Terminal_01x01; MountingHole_6.5mm_Pad_Via
D100, D200: SMBJ5.0A; D_SMB; LCSCStockCode C440263
F100, F200: mSMD150; Fuse_1812_4532Metric; PartNumber mSMD150; LCSCStockCode C70121
R121, R221: 220; R_0805_2012Metric; LCSCStockCode 0805W8F2200T5E
R122, R222: 4K7; R_0805_2012Metric; PartNumber ERJP06F4701V; LCSCStockCode C441984
RX1: B2B-PH-K(LF)(SN); JST_PH_B2B-PH-K_1x02_P2.00mm_Vertical; LCSCStockCode C2683610
TX1: B2B-PH-K(LF)(SN); JST_PH_B2B-PH-K_1x02_P2.00mm_Vertical; LCSCStockCode C2683610
U2, U4: EL3H7(B)(TA)-G; SOP-4_4.4x2.6mm_P1.27mm; LCSCStockCode C32565

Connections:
+VDC: D100.1 (K), F100.1, U4.4; also elsewhere on the board
-VDC: D200.2 (A), F200.2, R222.1, U4.2; also elsewhere on the board
GND: CENTER1.1, D100.2 (A), D200.1 (K), R122.1, RX1.2, U2.2; also elsewhere on the board
unnamed: +POS1.1, F100.2
unnamed: -NEG1.1, F200.1
unnamed: R121.1, U2.1
unnamed: R221.2, U4.1
unnamed: TX1.1, U2.3
unnamed: TX1.2, U2.4
RXD1: R122.2, U4.3; also elsewhere on the board
RXD2: R222.2, RX1.1; also elsewhere on the board
TXD1: R121.2; also elsewhere on the board
TXD2: R221.1; also elsewhere on the board

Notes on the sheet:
The Leaf cell is 2s2P with 3 connection terminals, +ve common -ve Voltage on one pack is measured between the -ve terminal and common. The voltage on the second pack measures between the +ve terminal and common. Each BMS is has its own supply: +ve terminal - common (common is negative) -ve terminal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
Wires from J2-P3 and J2-P4 go to a crip ring mounting point. This gives the -ve for the +POS BMS and the +ve for the -NEG side. YES.. again confusing.
+POS
Communications is done via Daisy-chain serial protocol. J2 Pin1-2 connects to RX2 Pin2-1 on the next board in sequence. The first board in the sequence, start of the daisy-chain, RX is connected to the WiFi controller TX output.
Serial output from '-NEG' terminal BMS is hardwired to the serial input of the'+POS' terminal BMS
+VDC is the common connection point with reference to the -NEG connection point
-NEG
::::NOTE:::: Once the 2pin connectors are soldered trim the legs as flush with the solder as possible.
mSMD150, 8V MAX, FUSE HOLD @ 1.5AMP, TRIP 3A

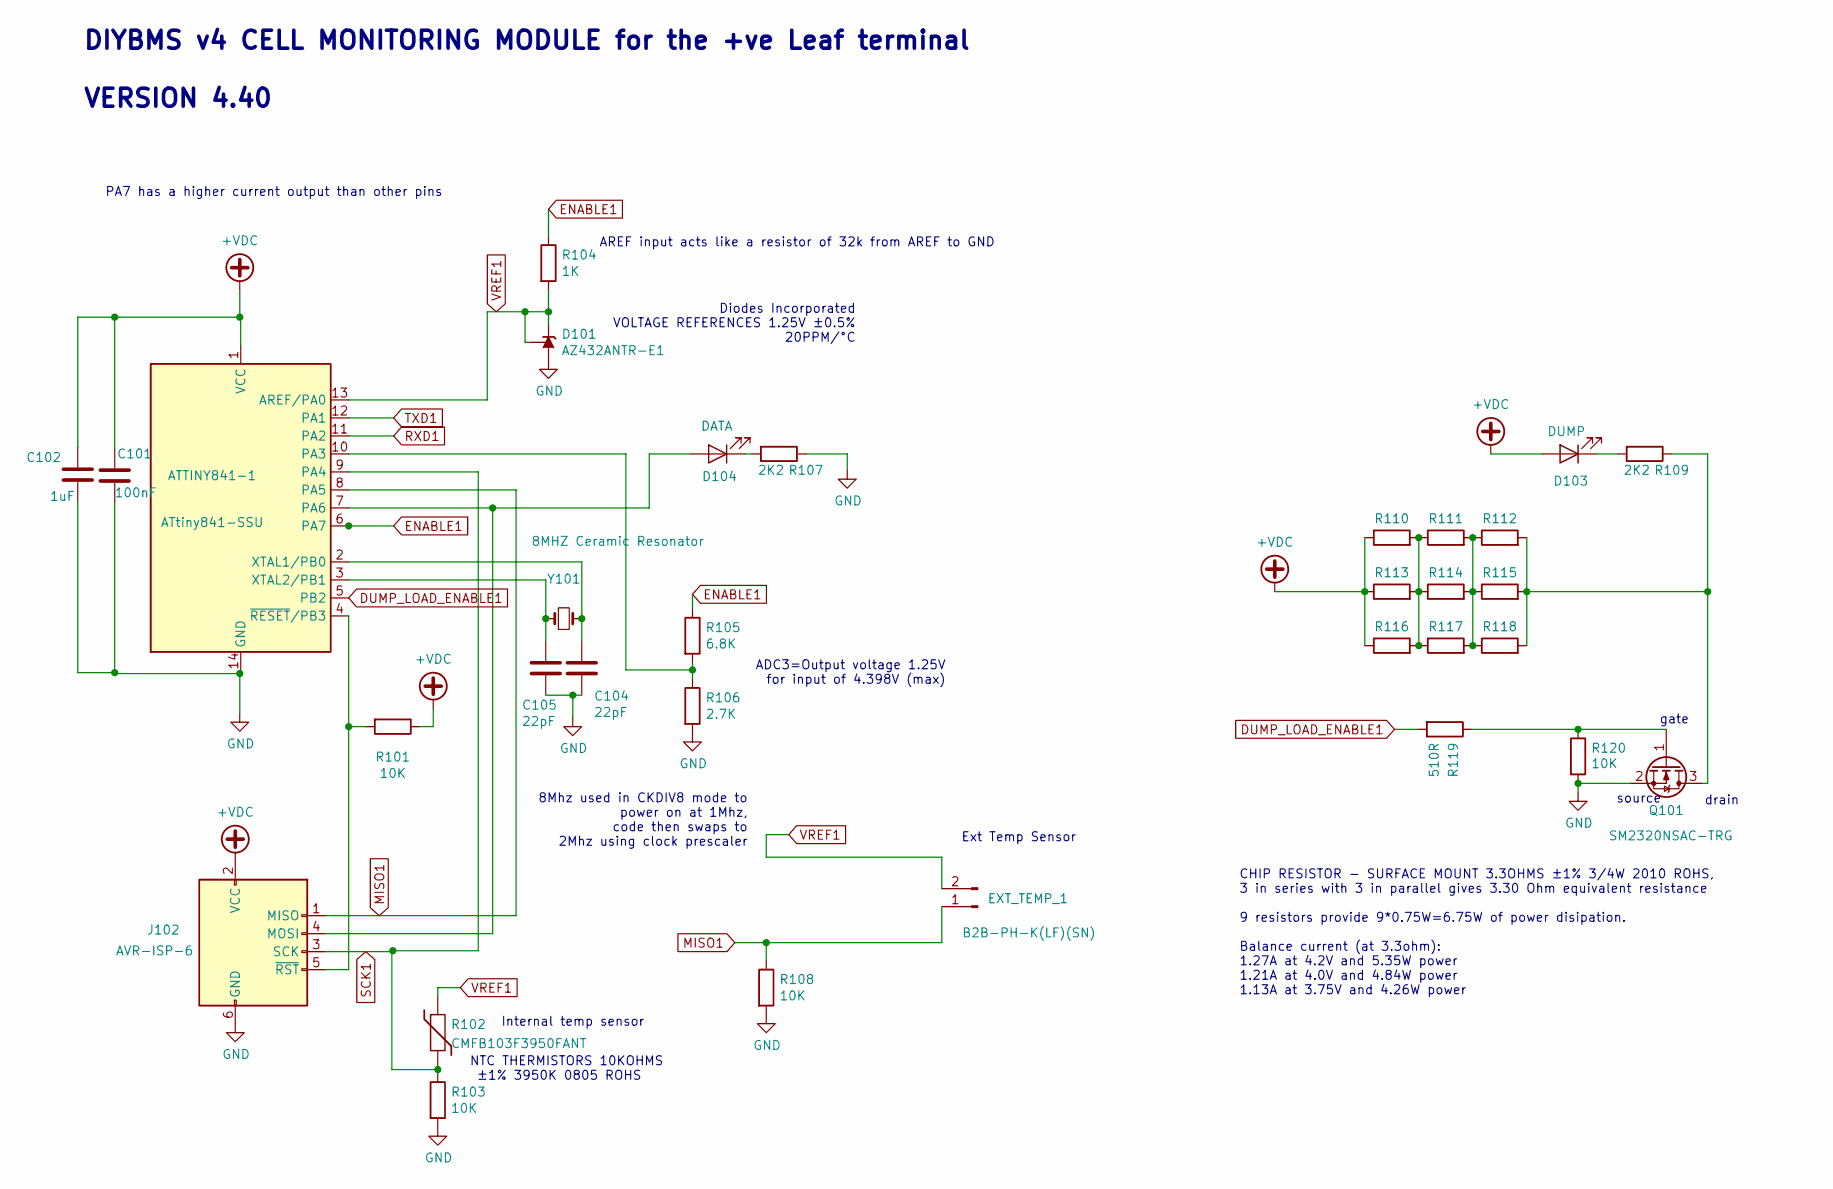
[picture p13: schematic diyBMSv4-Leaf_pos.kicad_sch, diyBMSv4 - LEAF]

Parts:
ATTINY841-1: ATtiny841-SSU; SOIC-14_3.9x8.7mm_P1.27mm; LCSCStockCode C219103
C101: 100nF; C_0805_2012Metric; PartNumber CC0805KRX7R9BB104; LCSCStockCode C49678
C102: 1uF; C_0805_2012Metric; PartNumber CL21B105KBFNNNE; LCSCStockCode C28323
C104, C105: 22pF; C_0805_2012Metric; PartNumber CL21C220JBANNNC; LCSCStockCode C1804
D101: AZ432ANTR-E1; SOT-23; PartNumber AZ432ANTR-E1; LCSCStockCode C84139
D103: DUMP; LED_0805_2012Metric; PartNumber NCD0805R1; LCSCStockCode C84256
D104: DATA; LED_0805_2012Metric; PartNumber NCD0805B2; LCSCStockCode C84259
EXT_TEMP_1: B2B-PH-K(LF)(SN); JST_PH_B2B-PH-K_1x02_P2.00mm_Vertical; LCSCStockCode C2683610
J102: AVR-ISP-6; PinHeader_2x03_P2.54mm_Vertical; LCSCStockCode C65114
Q101: SM2320NSAC-TRG; SOT-23; PartNumber SM2320NSAC-TRG; LCSCStockCode C368560
R101, R103, R108, R120: 10K; R_0805_2012Metric; PartNumber 0805W8F1002T5E; LCSCStockCode C17414
R102: CMFB103F3950FANT; R_0805_2012Metric; PartNumber CMFB103F3950FANT; LCSCStockCode C51597
R104: 1K; R_0805_2012Metric; PartNumber 0805W8F1001T5E; LCSCStockCode C17513
R105: 6.8K; R_0805_2012Metric; PartNumber 0805W8F6801T5E; LCSCStockCode C17772
R106: 2.7K; R_0805_2012Metric; PartNumber 0805W8F2701T5E; LCSCStockCode C17530
R107, R109: 2K2; R_0805_2012Metric; PartNumber 0805W8F2201T5E; LCSCStockCode C17520
R110, R111, R112, R113, R114, R115, R116, R117, R118: 3.3OHM 3/4W; R_2010_5025Metric; PartNumber 201007F330KT4E; LCSCStockCode C270971
R119: 510R; R_0805_2012Metric; PartNumber 0805W8F5100T5E; LCSCStockCode C17734
Y101: 8MHZ Ceramic Resonator; Crystal_SMD_5032-2Pin_5.0x3.2mm; PartNumber X50328MSB2GI; LCSCStockCode C115962

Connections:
+VDC: ATTINY841-1.1 (VCC), C101.1, C102.1, D103.2 (A), J102.2 (VCC), R101.1, R110.1, R113.1, R116.1; also elsewhere on the board
DUMP_LOAD_ENABLE1: ATTINY841-1.5 (PB2), R119.2
ENABLE1: ATTINY841-1.6 (PA7), R104.1, R105.1
GND: ATTINY841-1.14 (GND), C101.2, C102.2, C104.2, C105.2, D101.3 (A), J102.6 (GND), Q101.2 (S), R103.2, R106.2, R107.1, R108.2, R120.2; also elsewhere on the board
MISO1: ATTINY841-1.8 (PA5), EXT_TEMP_1.1, J102.1 (MISO), R108.1
unnamed: ATTINY841-1.2 (XTAL1/PB0), C104.1, Y101.2
unnamed: ATTINY841-1.3 (XTAL2/PB1), C105.1, Y101.1
unnamed: ATTINY841-1.4 (~RESET~/PB3), J102.5 (~RST), R101.2
unnamed: ATTINY841-1.7 (PA6), D104.2 (A), J102.4 (MOSI)
unnamed: ATTINY841-1.10 (PA3), R105.2, R106.1
unnamed: D103.1 (K), R109.2
unnamed: D104.1 (K), R107.2
unnamed: Q101.1 (G), R119.1, R120.1
unnamed: Q101.3 (D), R109.1, R112.2, R115.2, R118.2
unnamed: R110.2, R111.1, R113.2, R114.1, R116.2, R117.1
unnamed: R111.2, R112.1, R114.2, R115.1, R117.2, R118.1
RXD1: ATTINY841-1.11 (PA2); also elsewhere on the board
SCK1: ATTINY841-1.9 (PA4), J102.3 (SCK), R102.2, R103.1
TXD1: ATTINY841-1.12 (PA1); also elsewhere on the board
VREF1: ATTINY841-1.13 (AREF/PA0), D101.1 (REF), D101.2 (K), EXT_TEMP_1.2, R102.1, R104.2

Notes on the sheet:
DIYBMS v4 CELL MONITORING MODULE for the +ve Leaf terminal VERSION 4.40
PA7 has a higher current output than other pins
NTC THERMISTORS 10KOHMS ±1% 3950K 0805 ROHS
Internal temp sensor
AREF input acts like a resistor of 32k from AREF to GND
8Mhz used in CKDIV8 mode to power on at 1Mhz, code then swaps to 2Mhz using clock prescaler
Diodes Incorporated VOLTAGE REFERENCES 1.25V ±0.5% 20PPM/°C
ADC3=Output voltage 1.25V for input of 4.398V (max)
Ext Temp Sensor
CHIP RESISTOR - SURFACE MOUNT 3.3OHMS ±1% 3/4W 2010 ROHS, 3 in series with 3 in parallel gives 3.30 Ohm equivalent resistance 9 resistors provide 9*0.75W=6.75W of power disipation. Balance current (at 3.3ohm): 1.27A at 4.2V and 5.35W power 1.21A at 4.0V and 4.84W power 1.13A at 3.75V and 4.26W power
source
gate
drain

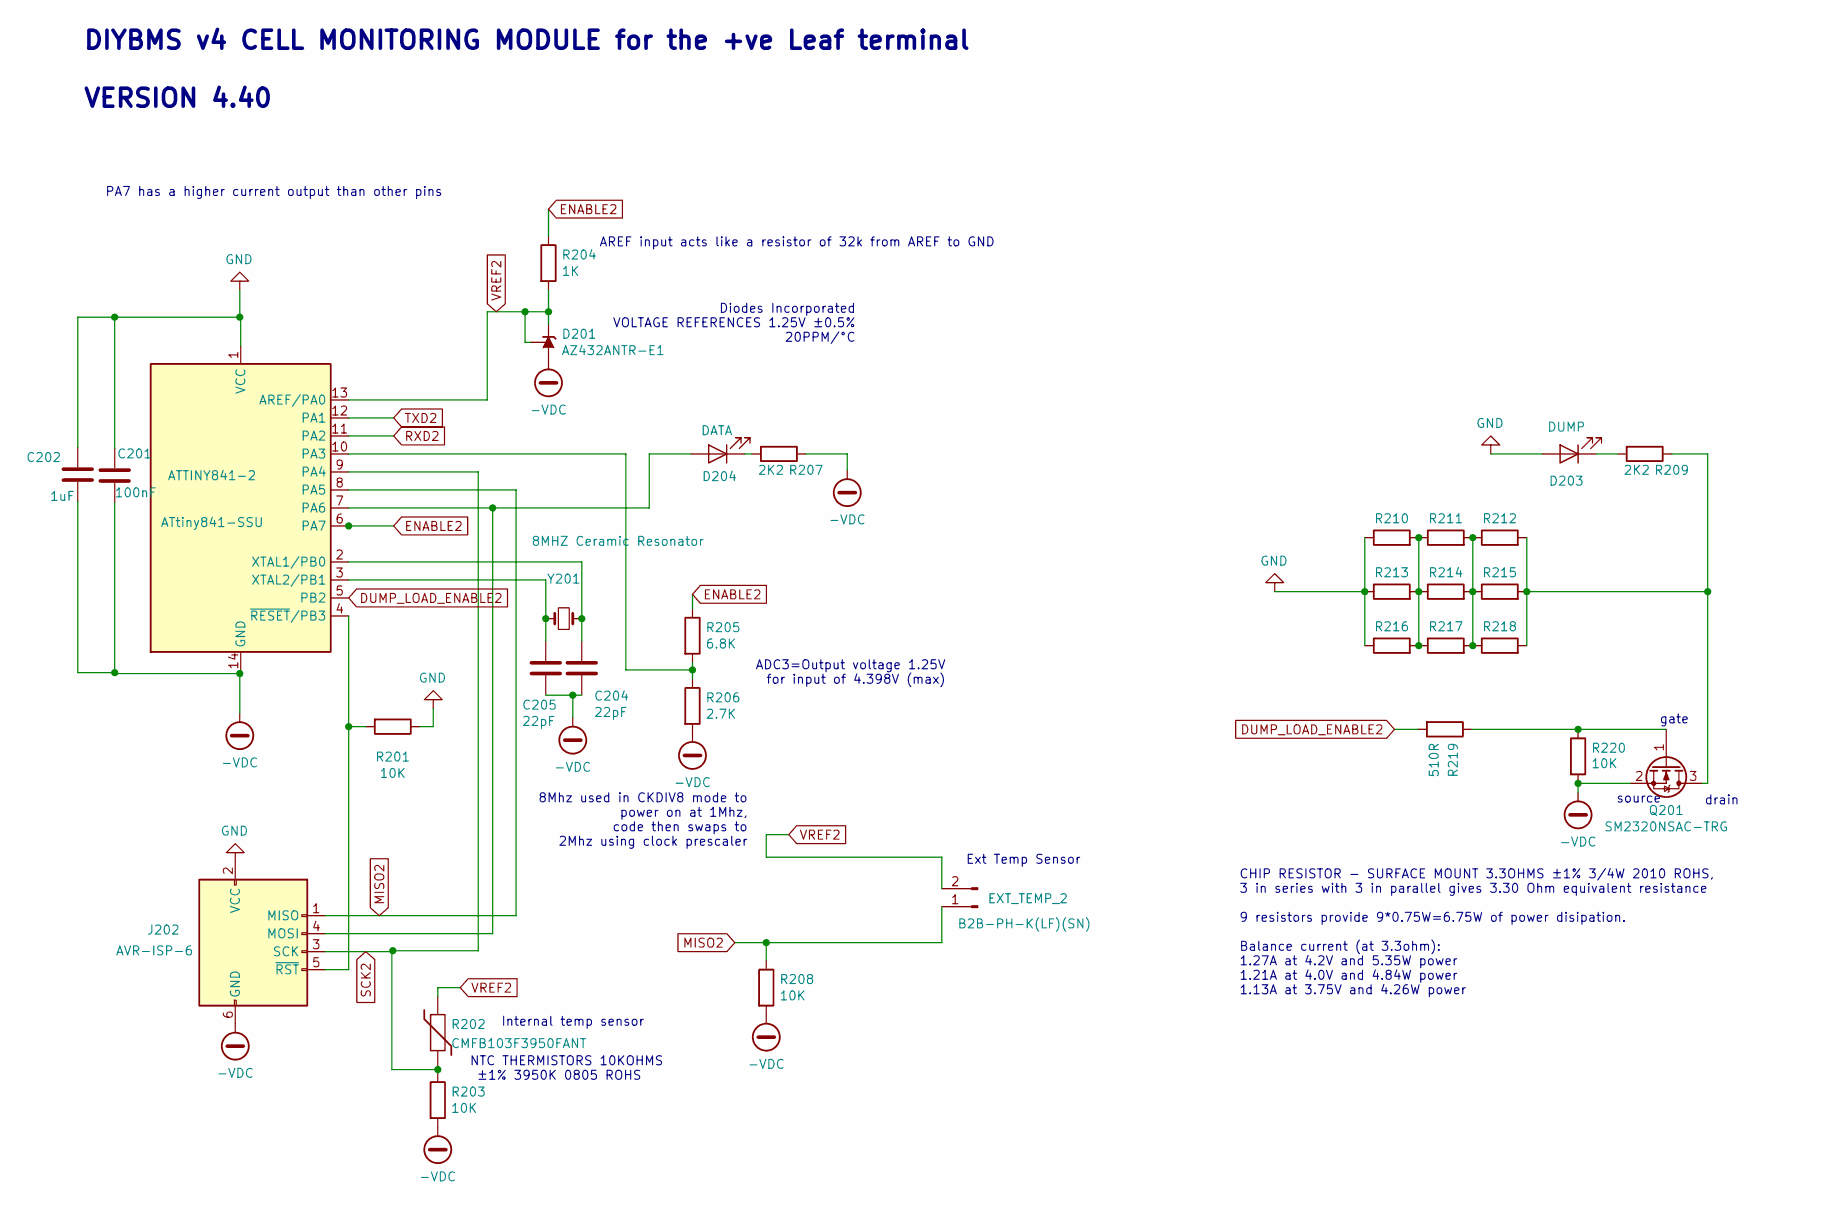
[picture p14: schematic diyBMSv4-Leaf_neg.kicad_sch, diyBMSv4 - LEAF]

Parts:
ATTINY841-2: ATtiny841-SSU; SOIC-14_3.9x8.7mm_P1.27mm; LCSCStockCode C219103
C201: 100nF; C_0805_2012Metric; PartNumber CC0805KRX7R9BB104; LCSCStockCode C49678
C202: 1uF; C_0805_2012Metric; PartNumber CL21B105KBFNNNE; LCSCStockCode C28323
C204, C205: 22pF; C_0805_2012Metric; PartNumber CL21C220JBANNNC; LCSCStockCode C1804
D201: AZ432ANTR-E1; SOT-23; PartNumber AZ432ANTR-E1; LCSCStockCode C84139
D203: DUMP; LED_0805_2012Metric; PartNumber NCD0805R1; LCSCStockCode C84256
D204: DATA; LED_0805_2012Metric; PartNumber NCD0805B2; LCSCStockCode C84259
EXT_TEMP_2: B2B-PH-K(LF)(SN); JST_PH_B2B-PH-K_1x02_P2.00mm_Vertical; LCSCStockCode C2683610
J202: AVR-ISP-6; PinHeader_2x03_P2.54mm_Vertical; LCSCStockCode C65114
Q201: SM2320NSAC-TRG; SOT-23; PartNumber SM2320NSAC-TRG; LCSCStockCode C368560
R201, R203, R208, R220: 10K; R_0805_2012Metric; PartNumber 0805W8F1002T5E; LCSCStockCode C17414
R202: CMFB103F3950FANT; R_0805_2012Metric; PartNumber CMFB103F3950FANT; LCSCStockCode C51597
R204: 1K; R_0805_2012Metric; PartNumber 0805W8F1001T5E; LCSCStockCode C17513
R205: 6.8K; R_0805_2012Metric; PartNumber 0805W8F6801T5E; LCSCStockCode C17772
R206: 2.7K; R_0805_2012Metric; PartNumber 0805W8F2701T5E; LCSCStockCode C17530
R207, R209: 2K2; R_0805_2012Metric; PartNumber 0805W8F2201T5E; LCSCStockCode C17520
R210, R211, R212, R213, R214, R215, R216, R217, R218: 3.3OHM 3/4W; R_2010_5025Metric; PartNumber 201007F330KT4E; LCSCStockCode C270971
R219: 510R; R_0805_2012Metric; PartNumber 0805W8F5100T5E; LCSCStockCode C17734
Y201: 8MHZ Ceramic Resonator; Crystal_SMD_5032-2Pin_5.0x3.2mm; PartNumber X50328MSB2GI; LCSCStockCode C115962

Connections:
-VDC: ATTINY841-2.14 (GND), C201.2, C202.2, C204.2, C205.2, D201.3 (A), J202.6 (GND), Q201.2 (S), R203.2, R206.2, R207.1, R208.2, R220.2; also elsewhere on the board
DUMP_LOAD_ENABLE2: ATTINY841-2.5 (PB2), R219.2
ENABLE2: ATTINY841-2.6 (PA7), R204.1, R205.1
GND: ATTINY841-2.1 (VCC), C201.1, C202.1, D203.2 (A), J202.2 (VCC), R201.1, R210.1, R213.1, R216.1; also elsewhere on the board
MISO2: ATTINY841-2.8 (PA5), EXT_TEMP_2.1, J202.1 (MISO), R208.1
unnamed: ATTINY841-2.2 (XTAL1/PB0), C204.1, Y201.2
unnamed: ATTINY841-2.3 (XTAL2/PB1), C205.1, Y201.1
unnamed: ATTINY841-2.4 (~RESET~/PB3), J202.5 (~RST), R201.2
unnamed: ATTINY841-2.7 (PA6), D204.2 (A), J202.4 (MOSI)
unnamed: ATTINY841-2.10 (PA3), R205.2, R206.1
unnamed: D203.1 (K), R209.2
unnamed: D204.1 (K), R207.2
unnamed: Q201.1 (G), R219.1, R220.1
unnamed: Q201.3 (D), R209.1, R212.2, R215.2, R218.2
unnamed: R210.2, R211.1, R213.2, R214.1, R216.2, R217.1
unnamed: R211.2, R212.1, R214.2, R215.1, R217.2, R218.1
RXD2: ATTINY841-2.11 (PA2); also elsewhere on the board
SCK2: ATTINY841-2.9 (PA4), J202.3 (SCK), R202.2, R203.1
TXD2: ATTINY841-2.12 (PA1); also elsewhere on the board
VREF2: ATTINY841-2.13 (AREF/PA0), D201.1 (REF), D201.2 (K), EXT_TEMP_2.2, R202.1, R204.2

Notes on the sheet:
DIYBMS v4 CELL MONITORING MODULE for the +ve Leaf terminal VERSION 4.40
PA7 has a higher current output than other pins
NTC THERMISTORS 10KOHMS ±1% 3950K 0805 ROHS
Internal temp sensor
AREF input acts like a resistor of 32k from AREF to GND
8Mhz used in CKDIV8 mode to power on at 1Mhz, code then swaps to 2Mhz using clock prescaler
Diodes Incorporated VOLTAGE REFERENCES 1.25V ±0.5% 20PPM/°C
ADC3=Output voltage 1.25V for input of 4.398V (max)
Ext Temp Sensor
CHIP RESISTOR - SURFACE MOUNT 3.3OHMS ±1% 3/4W 2010 ROHS, 3 in series with 3 in parallel gives 3.30 Ohm equivalent resistance 9 resistors provide 9*0.75W=6.75W of power disipation. Balance current (at 3.3ohm): 1.27A at 4.2V and 5.35W power 1.21A at 4.0V and 4.84W power 1.13A at 3.75V and 4.26W power
source
gate
drain

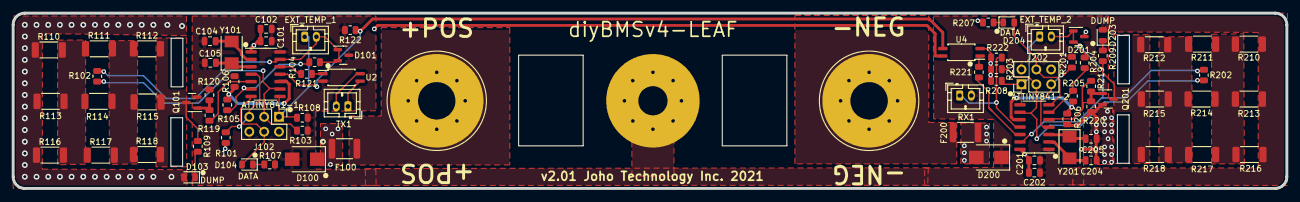
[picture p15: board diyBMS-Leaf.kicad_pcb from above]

Board: 2 copper layers, 218.0 x 30.0 mm, 79 parts (0 on the bottom side), 45 nets.

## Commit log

2020-03-15 Initial revision
    [diyBMS-Leaf.kicad_pcb, diyBMS-Leaf.sch, diyBMS-Leaf_BOM.xlsx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]
2021-03-11 Updated with latest (#3)
    * Updated with latest
    * V2.0.1
    [diyBMS-Leaf-B_Adhesive.gbr, diyBMS-Leaf-B_Cu.gbr, diyBMS-Leaf-B_Mask.gbr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]
